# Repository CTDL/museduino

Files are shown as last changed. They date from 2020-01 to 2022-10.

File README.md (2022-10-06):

# museduino
an open source electronics environment for exhibits

Docs: <a href="https://museduino.org">museduino.org</a>

## PCB design files and Schematics

All files are under <a href="https://github.com/CTDL/museduino/tree/master/hardware">hardware</a>  folder and subdivided by PCB design software.

ExpressPCB folder contains versions 2.2 and below. Kicad folder is organized by board name contains its own versions (3.0 or greater).

View changelog.md for further information on changes between versions.

## Tutorials and Circuit Diagrams
Content for workshops and Museduino guides can be found under 
<a href="https://github.com/CTDL/museduino/tree/master/tutorials">tutorials</a> folder.

## Solder Instructions
Component guides and step-by-step instructions coming soon.
<a href="https://github.com/CTDL/museduino/tree/master/solder-instructions">solder-instructions</a> folder.

## Open Source
Museduino 4.0 is certified as OSHWA-compliant open source hardware.

<a href="https://certification.oshwa.org/us002128.html">certification.oshwa.org/us002128.html</a>

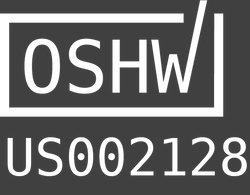
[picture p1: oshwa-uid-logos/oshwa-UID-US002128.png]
certification


## License

Licensing

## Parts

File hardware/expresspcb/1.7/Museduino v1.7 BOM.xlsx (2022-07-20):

BOM for Museduino v1.7 |  |  |  |  | ~cost
Part ID | Description |  |  | Vendor
D1 | T1 Green |  |  |  | 0.1
D2 | T1 Green |  |  |  | 0.1
D3 | T1 Green |  |  |  | 0.1
D4 | T1 Yellow |  |  |  | 0.1
J1 | 0.100 Header 8-pos |  |  |  | 0.1
J2 | 0.100 Header 8-pos |  |  |  | 0.1
J3 | 0.100 Header 6-pos |  |  |  | 0.1
J4 | 0.100 Header 6-pos |  |  |  | 0.1
J5 | RJ-45 Socket |  |  |  | 0.8
J6 | RJ-45 Socket |  |  |  | 0.8
J7 | RJ-45 Socket |  |  |  | 0.8
J8 | RJ-45 Socket |  |  |  | 0.8
J9 | Breadboard-friendly 2.1mm DC barrel jack[ID:373] |  |  | Adafruit | 0.86
J10 | RJ-45 Socket |  |  |  | 0.8
J11 | RJ-45 Socket |  |  |  | 0.8
J12 | 2.54mm/0.1" Pitch Terminal Block - 4-pin[ID:2137] |  |  | Adafruit | 1.4
J13 | RJ-45 Socket |  |  |  | 0.8
J14 | 2.54mm/0.1" Pitch Terminal Block - 4-pin[ID:2137] |  |  | Adafruit | 1.4
J15 | 2.54mm/0.1" Pitch Terminal Block - 4-pin[ID:2137] |  |  | Adafruit | 1.4
J16 | 2.54mm/0.1" Pitch Terminal Block - 4-pin[ID:2137] |  |  | Adafruit | 1.4
J17 | 2.54mm/0.1" Pitch Terminal Block - 4-pin[ID:2137] |  |  | Adafruit | 1.4
J18 | 2.54mm/0.1" Pitch Terminal Block - 4-pin[ID:2137] |  |  | Adafruit | 1.4
J19 | 0.100 4 pos male header |  |  |  | 0.1
J20 | 0.100 4 pos male header |  |  |  | 0.1
J21 | 0.100 4 pos male header |  |  |  | 0.1
J22 | 3.81mm terminal block | 1727010 (http://www.newark.com/webapp/wcs/stores/servlet/ProductDisplay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) |  | Newark | 1.04
J23 | 0.100 4 pos male header |  |  |  | 0.1
JP1 | 3 pos 0.100 jumper |  |  |  | 0.1
JP2 | 3 pos 0.100 jumper |  |  |  | 0.1
JP3 | 3 pos 0.100 jumper |  |  |  | 0.1
JP4 | 3 pos 0.100 jumper |  |  |  | 0.1
Q1 | TO-252 zxmn10A09K |  |  | Digikey | 1.4
Q2 | TO-252 zxmn10A09K |  |  |  | 1.4
Q3 | TO-252 zxmn10A09K |  |  |  | 1.4
R1 | 470 1/8W |  |  |  | 0.02
R2 | 220 |  |  |  | 0.02
R3 | 220 |  |  |  | 0.02
R4 | 470 |  |  |  | 0.02
R5 | 470 |  |  |  | 0.02
R6 | 470 |  |  |  | 0.02
R7 | 470 |  |  |  | 0.02
R8 | 470 |  |  |  | 0.02
R9 | 220 |  |  |  | 0.02
R10 | 1K |  |  |  | 0.02
SW1 | DPDT DIP GrayHill 76SD01T |  |  | Mouser | 3.3
SW2 | DPDT DIP GrayHill 76SD01T |  |  |  | 3.3
U1 | 7805 TO-220 |  |  |  | 0.5
 |  |  | Total Cost |  | 29 | plus other smorgasboard
 |  |  |  |  | Approximately $35 in parts.

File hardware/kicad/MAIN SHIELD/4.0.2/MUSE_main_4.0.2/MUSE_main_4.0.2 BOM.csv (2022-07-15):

Id | Designator | Package | Quantity | Designation | Supplier and ref
1 | J1,J4,J11,J14 | Pin_Header_Straight_1x08_Pitch2.54mm | 4 | CONN_01X08
2 | J2,J12 | Pin_Header_Straight_1x10_Pitch2.54mm | 2 | CONN_01X10
3 | J3,J13 | Pin_Header_Straight_1x06_Pitch2.54mm | 2 | CONN_01X06
4 | J5,J8,J6 | RJ45_8 | 3 | CONN_01X08
5 | J7 | RJ45_8 | 1 | CONN_01X08
6 | D1 | LED_D3.0mm | 1 | LED
7 | J9 | BARREL_JACK_RND | 1 | BARREL_JACK
8 | R1 | R_Axial_DIN0204_L3.6mm_D1.6mm_P7.62mm_Horizontal | 1 | 470
9 | U1 | TO-220_Horizontal | 1 | LM7805CT
10 | JP1 | Pin_Header_Straight_1x03_Pitch2.54mm | 1 | CONN_01X03
11 | JP5,JP6,JP2,JP3 | Pin_Header_Straight_2x03_Pitch2.54mm | 4 | CONN_02X03
12 | G*** | open_hdwe_rev | 1 | LOGO

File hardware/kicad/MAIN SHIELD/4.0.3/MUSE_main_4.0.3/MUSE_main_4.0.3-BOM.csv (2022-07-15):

Id | Designator | Package | Quantity | Designation | Supplier and ref
1 | JP1 | Pin_Header_Straight_1x03_Pitch2.54mm | 1 | CONN_01X03
2 | J6,J5,J8 | RJ45_8 | 3 | CONN_01X08
3 | J1,J4,J11,J14 | Pin_Header_Straight_1x08_Pitch2.54mm | 4 | CONN_01X08
4 | J2,J12 | Pin_Header_Straight_1x10_Pitch2.54mm | 2 | CONN_01X10
5 | J3,J13 | Pin_Header_Straight_1x06_Pitch2.54mm | 2 | CONN_01X06
6 | J7 | RJ45_8 | 1 | CONN_01X08
7 | D1 | LED_D3.0mm | 1 | LED
8 | U1 | TO-220_Horizontal | 1 | LM7805CT
9 | JP5,JP6,JP2,JP3 | Pin_Header_Straight_2x03_Pitch2.54mm | 4 | CONN_02X03
10 | R1 | R_Axial_DIN0204_L3.6mm_D1.6mm_P7.62mm_Horizontal | 1 | 470
11 | G*** | open_hdwe_rev | 1 | LOGO
12 | J9 | BARREL_JACK_RND | 1 | BARREL_JACK

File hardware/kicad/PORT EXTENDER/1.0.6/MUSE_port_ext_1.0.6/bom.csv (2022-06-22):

value | footprint | libsource/_lib | libsource/_part | libsource/_description | sheetpath/_names | sheetpath/_tstamps | tstamp | _ref | datasheet | fields/field/0/_name | fields/field/0/__text | fields/field/1/_name | fields/field/1/__text | fields/field/2/_name | fields/field/2/__text | fields/field/3/_name | fields/field/3/__text | fields/field/4/_name | fields/field/4/__text | fields/field/5/_name | fields/field/5/__text | fields/field/6/_name | fields/field/6/__text | fields/field/7/_name | fields/field/7/__text | fields/field/8/_name | fields/field/8/__text
RJ45_01X08 | Connectors:RJ45_8 | Connector_Generic | Conn_01x08 | Generic connector, single row, 01x08, script generated (kicad-library-utils/schlib/autogen/connector/) | / | / | 5A0F6021 | J1
RJ45_01X08 | Connectors:RJ45_8 | Connector_Generic | Conn_01x08 | Generic connector, single row, 01x08, script generated (kicad-library-utils/schlib/autogen/connector/) | / | / | 5A1D9F02 | J3
LED | LEDs:LED_D3.0mm | Device | LED | LED generic | / | / | 5A1DA0EA | D1
470 | Resistors_THT:R_Axial_DIN0204_L3.6mm_D1.6mm_P7.62mm_Horizontal | Device | R | Resistor | / | / | 5A1DA161 | R3
RJ45_01X08 | Connectors:RJ45_8 | Connector_Generic | Conn_01x08 | Generic connector, single row, 01x08, script generated (kicad-library-utils/schlib/autogen/connector/) | / | / | 5B0AEDCC | J4
RJ45_01X08 | Connectors:RJ45_8 | Connector_Generic | Conn_01x08 | Generic connector, single row, 01x08, script generated (kicad-library-utils/schlib/autogen/connector/) | / | / | 5B16A2C0 | J2
RJ45_01X08 | Connectors:RJ45_8 | Connector_Generic | Conn_01x08 | Generic connector, single row, 01x08, script generated (kicad-library-utils/schlib/autogen/connector/) | / | / | 5B16A32D | J5
CD74HC4051E | digikey-footprints:DIP-16_W7.62mm | dk_Interface-Analog-Switches-Multiplexers-Demultiplexers | CD74HC4051E | IC MUX/DEMUX 8X1 16DIP | / | / | 5B16ED2B | U4 | http://www.ti.com/lit/ds/symlink/cd74hc4051.pdf | Category | Integrated Circuits (ICs) | DK_Datasheet_Link | http://www.ti.com/lit/ds/symlink/cd74hc4051.pdf | DK_Detail_Page | /product-detail/en/texas-instruments/CD74HC4051E/296-12810-5-ND/475938 | Description | IC MUX/DEMUX 8X1 16DIP | Digi-Key_PN | 296-12810-5-ND | Family | Interface - Analog Switches, Multiplexers, Demultiplexers | MPN | CD74HC4051E | Manufacturer | Texas Instruments | Status | Active
CD74HC4067SM96 | digikey-footprints:SSOP-24_W5.30mm | dk_Interface-Analog-Switches-Multiplexers-Demultiplexers | CD74HC4067SM96 | IC MUX/DEMUX 1X16 24SSOP | / | / | 5B16F5DB | U3 | http://www.ti.com/lit/ds/symlink/cd74hc4067.pdf | Category | Integrated Circuits (ICs) | DK_Datasheet_Link | http://www.ti.com/lit/ds/symlink/cd74hc4067.pdf | DK_Detail_Page | /product-detail/en/texas-instruments/CD74HC4067SM96/296-9226-1-ND/376978 | Description | IC MUX/DEMUX 1X16 24SSOP | Digi-Key_PN | 296-9226-1-ND | Family | Interface - Analog Switches, Multiplexers, Demultiplexers | MPN | CD74HC4067SM96 | Manufacturer | Texas Instruments | Status | Active
MCP23017-E_SP | digikey-footprints:DIP-28_W7.62mm | dk_Interface-I-O-Expanders | MCP23017-E_SP | IC I/O EXPANDER I2C 16B 28SDIP | / | / | 5B1C5702 | U2 | http://www.microchip.com/mymicrochip/filehandler.aspx?ddocname=en023709 | Category | Integrated Circuits (ICs) | DK_Datasheet_Link | http://www.microchip.com/mymicrochip/filehandler.aspx?ddocname=en023709 | DK_Detail_Page | /product-detail/en/microchip-technology/MCP23017-E-SP/MCP23017-E-SP-ND/894272 | Description | IC I/O EXPANDER I2C 16B 28SDIP | Digi-Key_PN | MCP23017-E/SP-ND | Family | Interface - I/O Expanders | MPN | MCP23017-E/SP | Manufacturer | Microchip Technology | Status | Active
MCP23017-E_SP | digikey-footprints:DIP-28_W7.62mm | dk_Interface-I-O-Expanders | MCP23017-E_SP | IC I/O EXPANDER I2C 16B 28SDIP | / | / | 5B1C5A45 | U1 | http://www.microchip.com/mymicrochip/filehandler.aspx?ddocname=en023709 | Category | Integrated Circuits (ICs) | DK_Datasheet_Link | http://www.microchip.com/mymicrochip/filehandler.aspx?ddocname=en023709 | DK_Detail_Page | /product-detail/en/microchip-technology/MCP23017-E-SP/MCP23017-E-SP-ND/894272 | Description | IC I/O EXPANDER I2C 16B 28SDIP | Digi-Key_PN | MCP23017-E/SP-ND | Family | Interface - I/O Expanders | MPN | MCP23017-E/SP | Manufacturer | Microchip Technology | Status | Active
0.1 | Capacitors_THT:CP_Radial_Tantal_D4.5mm_P2.50mm | Device | CP | Polarised capacitor | / | / | 5B1DB3D3 | C1
10K | Resistors_THT:R_Axial_DIN0204_L3.6mm_D1.6mm_P7.62mm_Horizontal | Device | R | Resistor | / | / | 5B1E0CC2 | R1
RJ45_01X08 | Connectors:RJ45_8 | Connector_Generic | Conn_01x08 | Generic connector, single row, 01x08, script generated (kicad-library-utils/schlib/autogen/connector/) | / | / | 5B20212D | J6
RJ45_01X08 | Connectors:RJ45_8 | Connector_Generic | Conn_01x08 | Generic connector, single row, 01x08, script generated (kicad-library-utils/schlib/autogen/connector/) | / | / | 5B202153 | J7
RJ45_01X08 | Connectors:RJ45_8 | Connector_Generic | Conn_01x08 | Generic connector, single row, 01x08, script generated (kicad-library-utils/schlib/autogen/connector/) | / | / | 5B202174 | J8
RJ45_01X08 | Connectors:RJ45_8 | Connector_Generic | Conn_01x08 | Generic connector, single row, 01x08, script generated (kicad-library-utils/schlib/autogen/connector/) | / | / | 5B202231 | J10
RJ45_01X08 | Connectors:RJ45_8 | Connector_Generic | Conn_01x08 | Generic connector, single row, 01x08, script generated (kicad-library-utils/schlib/autogen/connector/) | / | / | 5B202257 | J9
10K | Resistors_THT:R_Axial_DIN0204_L3.6mm_D1.6mm_P7.62mm_Horizontal | Device | R | Resistor | / | / | 5B20789B | R2
10K | Resistors_THT:R_Axial_DIN0204_L3.6mm_D1.6mm_P7.62mm_Horizontal | Device | R | Resistor | / | / | 5B2AD4FA | R4
10K | Resistors_THT:R_Axial_DIN0204_L3.6mm_D1.6mm_P7.62mm_Horizontal | Device | R | Resistor | / | / | 5B2AE901 | R5
Conn_01x03 | Pin_Headers:Pin_Header_Straight_1x03_Pitch2.54mm | Connector_Generic | Conn_01x03 | Generic connector, single row, 01x03, script generated (kicad-library-utils/schlib/autogen/connector/) | / | / | 5B4A910C | JMP4
Conn_01x03 | Pin_Headers:Pin_Header_Straight_1x03_Pitch2.54mm | Connector_Generic | Conn_01x03 | Generic connector, single row, 01x03, script generated (kicad-library-utils/schlib/autogen/connector/) | / | / | 5B4A9348 | JMP5
Conn_01x03 | Pin_Headers:Pin_Header_Straight_1x03_Pitch2.54mm | Connector_Generic | Conn_01x03 | Generic connector, single row, 01x03, script generated (kicad-library-utils/schlib/autogen/connector/) | / | / | 5B4A93D5 | JMP6
Conn_01x03 | Pin_Headers:Pin_Header_Straight_1x03_Pitch2.54mm | Connector_Generic | Conn_01x03 | Generic connector, single row, 01x03, script generated (kicad-library-utils/schlib/autogen/connector/) | / | / | 5B4A7C88 | JMP1
Conn_01x03 | Pin_Headers:Pin_Header_Straight_1x03_Pitch2.54mm | Connector_Generic | Conn_01x03 | Generic connector, single row, 01x03, script generated (kicad-library-utils/schlib/autogen/connector/) | / | / | 5B4A7C8E | JMP2
Conn_01x03 | Pin_Headers:Pin_Header_Straight_1x03_Pitch2.54mm | Connector_Generic | Conn_01x03 | Generic connector, single row, 01x03, script generated (kicad-library-utils/schlib/autogen/connector/) | / | / | 5B4A7C94 | JMP3
Conn_01x09 | Pin_Headers:Pin_Header_Straight_1x09_Pitch2.54mm | Connector_Generic | Conn_01x09 | Generic connector, single row, 01x09, script generated (kicad-library-utils/schlib/autogen/connector/) | / | / | 5B4AA3C8 | J11
Conn_01x09 | Pin_Headers:Pin_Header_Straight_1x09_Pitch2.54mm | Connector_Generic | Conn_01x09 | Generic connector, single row, 01x09, script generated (kicad-library-utils/schlib/autogen/connector/) | / | / | 5B4B25C7 | J13
Conn_01x09 | Pin_Headers:Pin_Header_Straight_1x09_Pitch2.54mm | Connector_Generic | Conn_01x09 | Generic connector, single row, 01x09, script generated (kicad-library-utils/schlib/autogen/connector/) | / | / | 5B4B267D | J12
4.7K | Resistors_THT:R_Axial_DIN0204_L3.6mm_D1.6mm_P7.62mm_Horizontal | Device | R | Resistor | / | / | 5B625EDE | R6
4.7K | Resistors_THT:R_Axial_DIN0204_L3.6mm_D1.6mm_P7.62mm_Horizontal | Device | R | Resistor | / | / | 5B62623C | R7

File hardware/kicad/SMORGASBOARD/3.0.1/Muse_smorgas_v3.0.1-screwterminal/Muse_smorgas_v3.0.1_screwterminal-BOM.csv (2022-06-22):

Id | Designator | Package | Quantity | Designation | Supplier and ref
1 | J1,J2 | RJ45_8 | 2 | RJ45_01X08
2 | R1 | R_Axial_DIN0204_L3.6mm_D1.6mm_P7.62mm_Horizontal | 1 | 470
3 | Mount_hole,Mount_Hole | MountingHole_3.2mm_M3 | 2 | MountingHole_3.2mm_M3
4 | D1 | LED_D3.0mm | 1 | LED
5 | R2 | R_Axial_DIN0207_L6.3mm_D2.5mm_P10.16mm_Horizontal | 1 | 220
6 | R3,R4 | R_Axial_DIN0207_L6.3mm_D2.5mm_P10.16mm_Horizontal | 2 | 470
7 | J4,J5,J6,J7,J3 | Screw_Header_Straight_1x04_Pitch2.54mm | 5 | CONN_01X04
8 | Q1 | TO-251-1EP_IPAK_Horizontal_smorg | 1 | NTD3055L104-1G

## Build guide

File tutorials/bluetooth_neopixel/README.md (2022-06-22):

Puppet Theater Example Code

This code includes the Adafruit_BluefruitLE_nRF51 library.

Modified "Controller" Example to include Neopixel strand on pin 6. 

Dowload the Bluefruit LE Connect App to use color picker to change Neopixel color.

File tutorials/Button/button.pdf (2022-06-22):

# Button Tutorial

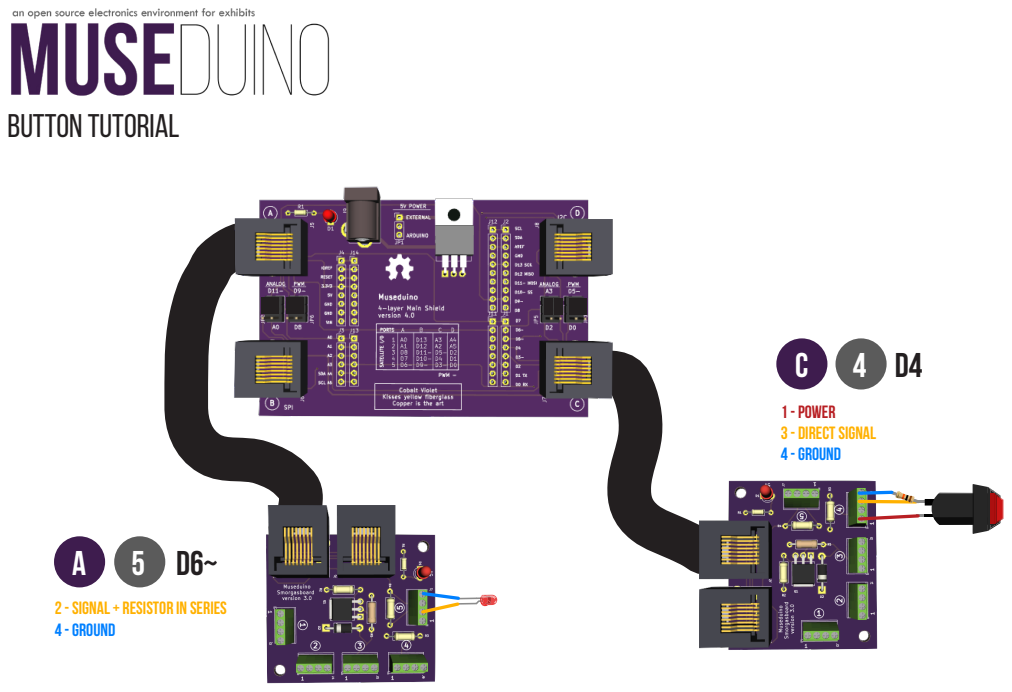
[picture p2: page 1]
1 - POWER 3 - Direct SIGNAL 4 - GROUND

2 - SIGNAL + RESISTOR IN SERIES
4 - GROUND

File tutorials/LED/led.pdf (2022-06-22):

# Button Tutorial

1 - POWER 3 - Direct SIGNAL 4 - GROUND

2 - SIGNAL + RESISTOR IN SERIES
4 - GROUND

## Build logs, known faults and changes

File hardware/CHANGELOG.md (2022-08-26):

# v4.0.3 (Dec 2019)

Fixed main shield labels on Analog select. 

# v4.0.2 (July 2018)

Kicad 5 update. Adjusted main shield labels.

Additional Satellite board named Port Extender is designed for projects that need to control more input and output devices.

#### Port Extender v1.0 
The Port Extender board was designed for use with the dedicated i2c port, Port D on the Main Shield and intended for projects that need to control more input and output devices. The Port Extender is equipped with two MCP23017 i2c 16-bit i/o digital port expanders, a CD74HC4051 8-channel multiplexer, and a CD74HC4067 16-channel multiplexer.  The Port Extender uses i2c pins (A4/A5 on Arduino Uno), analog pin (A3), and a PWM pin (D5~) in order to increase the number of usable digital, analog, and PWM pins.

# v4.0 (May 2018)

Adjusted main shield pin configuration. 

##### Analog Select on Main Shield

The Museduino main shield now allows distributed Analog pins to switch between ports. For example, pin D11~ on port B can switch places with pin A0 on port A. Pin A3 on Port C can also switch with Pin D2 on port D. This feature is useful when you need an extra Analog pin to be accessed from a different port. Intended for use with optional Port Extender.

##### New Distrubuted I/O

The Museduino shield distributes 20 Arduino pins between 4 CAT5/RJ-45 “ports”. A Satellite board connected on either port allows access to 5 specific Arduino pins to be used for sensors/actuators. The shield and satellite boards have a labeled solder mask to assist with configuration. Ports are labeled with a circled A, B, C, or D on the shield. The 5 Satellite I/O pins are labeled with a circled number 1 through 5 on the Satellite boards.

|  | A | B | C | D |	
| --- | --- | --- | --- | --- |
| 1 | A0  | D13  | * A3 | A4 |
| 2 | A1  | D12  | A2 | A5 |
| 3 | * D8  | D11~  | ** D5~ | * D2 |
| 4  | D7  | D10~  | D4 | D1 |
| 5  | D6~  | * D9~  | D3~ | ** D0 |

~ arduino pwm pin
* pwm switch

** analog switch

# v3 (Jan 2018)

All boards redesigned with Kicad 4. No functionaly changed, but replaced DPDT switch on main shield due to cost increase.  

Printed small run for testing purposes. 

# v2.2 (June 2015) 

Designed with Express PCB

No changes to schematic. Improved parts layout on pcb. 

# v2.0 (June 2015)

Designed with Express PCB. 

All i/o on satellite boards now use 4 pin screw terminals instead of header pins.

Improvements to overall pcb label design. Ports and satellite i/o labels use circled letter or number to match charts in documentation. 

##### New Distrubuted I/O labels

The Museduino distributes 5 different Arduino pins on ports A, B, C, or D labeled on the shield. A satellite connected on either port allows access to pins labeled 1, 2, 3, 4, or 5.

| ports | A | B | C | D |
| --- | --- | --- | --- | --- |
| 1 | A0  | D13  | A2 | A4 |
| 2 | A1  | D12  | A3 | A5 |
| 3 | * D8  | D11~  | D5~ | * D2 |
| 4 | D7  | D10~  | D4 | D1 |
| 5 | D6~  | * D9~  | * D3~ | D0 |

~ arduino pwm pin
* pwm switch

# v1.7 (May 2015)
Designed with Express PCB

Simplified labelling for Distributed I/O on all boards and chart using letters and numbers.

##### New Distrubuted I/O chart

The Museduino distributes 5 different Arduino pins on ports A, B, C, or D labeled on the shield. A satellite (S) connected on either port allows access to arduino pins labeled 1, 2, 3, 4, or 5.

| s | A | B | C | D |
| --- | --- | --- | --- | --- |
| 1 | A0  | D13  | A2 | A4 |
| 2 | A1  | D12  | A3 | A5 |
| 3 | * D8  | D11~  | D5~ | * D2 |
| 4 | D7  | D10~  | D4 | D1 |
| 5 | D6~  | * D9~  | * D3~ | D0 |

~ arduino pwm pin
* pwm switch

# v1.5 (March 2015)

Designed with Express PCB

New labels on PCB and to match Distributed I/O chart.

Main shield allows distributed PWM pins to switch between ports (cat5 pinout). For example, pin D9~ on port B can switch places with pin D8 on port A. Pin D3~ on Port D can also switch with Pin D2 on port C. This feature is useful when you need an extra PWM pin to be accessed from a Satellite board.

#### Smorgasboard 
Smorgasboard satellite board has 5 sets of headers for connecting to sensors/actuators labeled A through E in the schematic. Each i/o has its own pin configuration. 

A, B - power, signal pin, signal pin, ground pin
C - power, signal with open drain to ground (mosfet), direct signal, ground pin
D, E - power, signal pin with resistor n series, signal pin, ground pin

##### External Power board 
Additional Satellite board named External Power board is designed for sensor and actuators that require their own external power supply (NeoPixels, DC Motors, etc). Since satellites connected via CAT5 cables can be as long or short as needed, this board is particularly useful for large-scale installations.

External Power satellite board has 5 sets of headers for connecting to sensors/actuators labeled A through E in the schematic. Each i/o has its own pin configuration.  

A, B - power, signal pin, signal pin, ground pin
C, E - power, signal with open drain to ground (mosfet), direct signal, ground pin
D - power, signal pin, signal pin with resistor n series, ground pin

C, D and E contains a jumper that allows you to switch voltage between 5v from cat5, or voltage from the external power source. 

##### New Distrubuted I/O chart

The Museduino distributes 5 different Arduino pins on ports A, B, C, or D labeled on the shield. A satellite (S) connected on either port allows access to the specified Arduino pins used for sensors/actuators. 

| s  | s | A | B | C | D |
| --- | --- | --- | --- | --- | --- |
| smorgasboard pins  |  ext power pins | j5 | j6 | j8 | j7 |	
| j14 | j19 | A0  | D13  | A2 | A4 |
| j16  | j20 | A1  | D12  | A3 | A5 |
| j12  | j21 | * D8  | D11~  | D5~ | * D2 |
| j15  | j18 | D7  | D10~  | D4 | D1 |
| j17  | j23 | D6~  | * D9~  | * D3~ | D0 |

~ arduino pwm pin
* pwm switch

# v1.3

Designed with Express PCB. Printed small run for testing purposes. 

Changes to pin configuration to allow for pin swapping between between PWM pins.  

##### PWM Switches

v1.3 Main shield allows distributed PWM pins to switch between ports. For example, pin D9~ on j6 can switch places with pin D8 on j5. Pin D3~ on j7 can also switch with Pin D2 on j8. This feature is useful when you need an extra PWM pin to be accessed from a Satellite board.

#### Smorgasboard 
Smorgasboard satellite board has 5 sets of header pins for connecting to sensors/actuators. Each i/o has its own power, signal pin, optional signal pin with resistor in series, and ground pin. 

##### Distrubuted I/O chart

| pins  | j5 | j6 | j7 | j8 |	
| --- | --- | --- | --- | --- |
| j14 | A0  | D13  | A4 | A2 |
| j16  | A1  | D12  | A5 | A3 |
| j12  | * D8  | D11~  | * D2 | D5~ |
| j15  | D7  | D10~  | D1 | D4 |
| j17  | D6~  | * D9~ | D0 | * D3~ |

~ arduino pwm pin
* pwm switch

# v1.0 (Dec 2014)

Designed with Express PCB

The Museduino distributes Arduino Uno pins via Smorgasboard Satellites boards connected to CAT5/RJ45 ports on the main shield. Each port allows access to 5 distinct Arduino pins used for sensors/actuators.

The Museduino shield includes an external power jumper which allows for choice in power supply: 5V from the Arduino or an external source.

The Satellite board, named smorgasboard has pinout to allow for a wide range of sensor and actuator configurations from any CAT5/RJ45 port.

##### Distrubuted I/O chart

| pins  | j5 | j6 | j7 | j8 |	
| --- | --- | --- | --- | --- |
| j14 | A0  | D13  | A4 | A2 |
| j16  | A1  | D12  | A5 | A3 |
| j12  | D8  | D11~  | D2 | D5~ |
| j15  | D7  | D10~  | D1 | D4 |
| j17  | D6~  | D9~  | D0 | D3~ |

~ arduino pwm pin

#### Smorgasboard 
Smorgasboard satellite board has row of ground and power pins and 5 connections for various types of i/o.

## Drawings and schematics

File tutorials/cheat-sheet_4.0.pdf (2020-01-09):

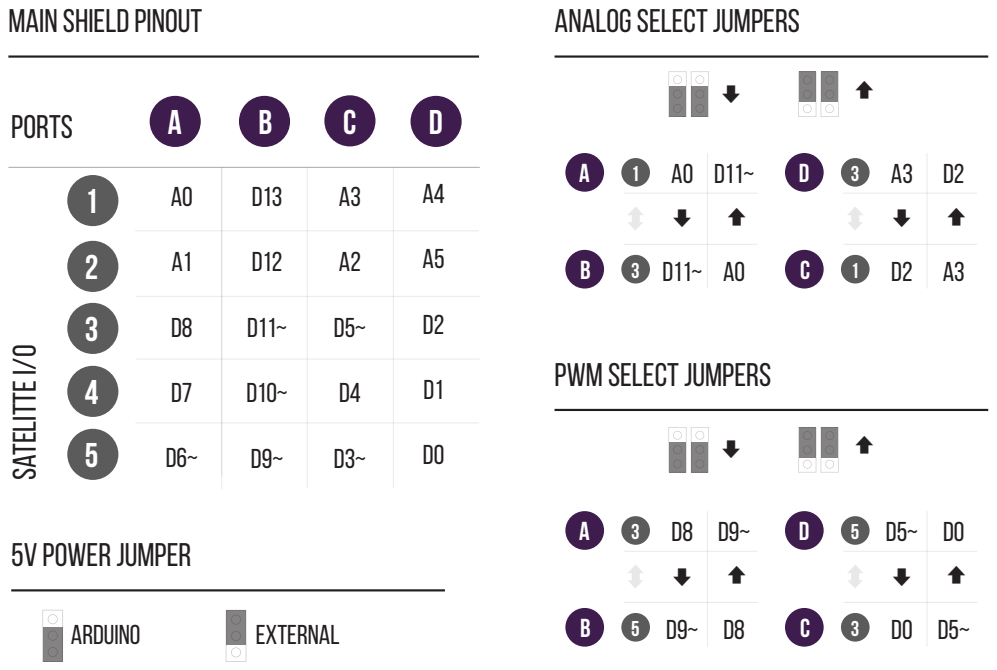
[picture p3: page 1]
SatelitTe I/O; Ports; 5v POWER JUMPER; ARDUINO; EXTERNAL

Main Shield Pinout

ANALOG SELECT JUMPERS

PWM SELECT JUMPERS

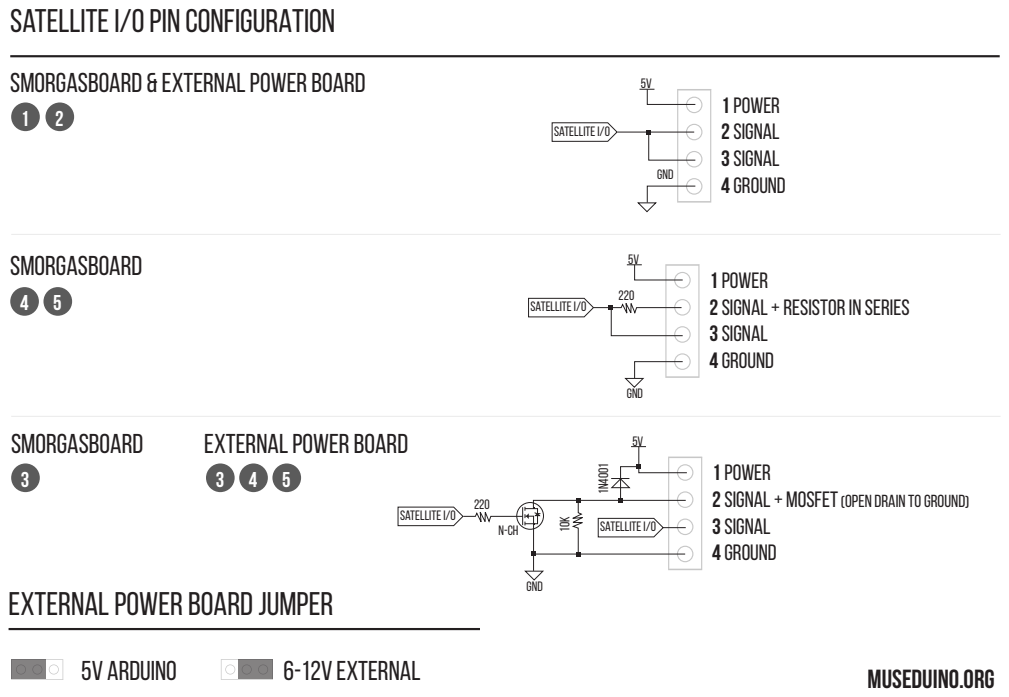
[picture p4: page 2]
SMOrgasboard; 5v ARDUINO; 6-12V EXTERNAL; Museduino.org; 1 Power 2 SIgnal 3 SIGNAL 4 GROUND; SatelliTe i/0; GND; SatelliTe i/0 ¹N400¹

Satellite i/0 PIN CONFIGURATION

SMOrgasboard & External PoWer BOARD

1 POWER
2 SIGNAl + Resistor in SeriEs
3 SIGNAL
4 GROUND

EXTERNAL POWER BOARD

2 SIGNAL + MOSFET(open Drain to GROUND)
3 SIGNAl

EXTERNAL POWER Board JUMPER

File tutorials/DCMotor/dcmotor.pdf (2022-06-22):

# DC Motor Tutorial

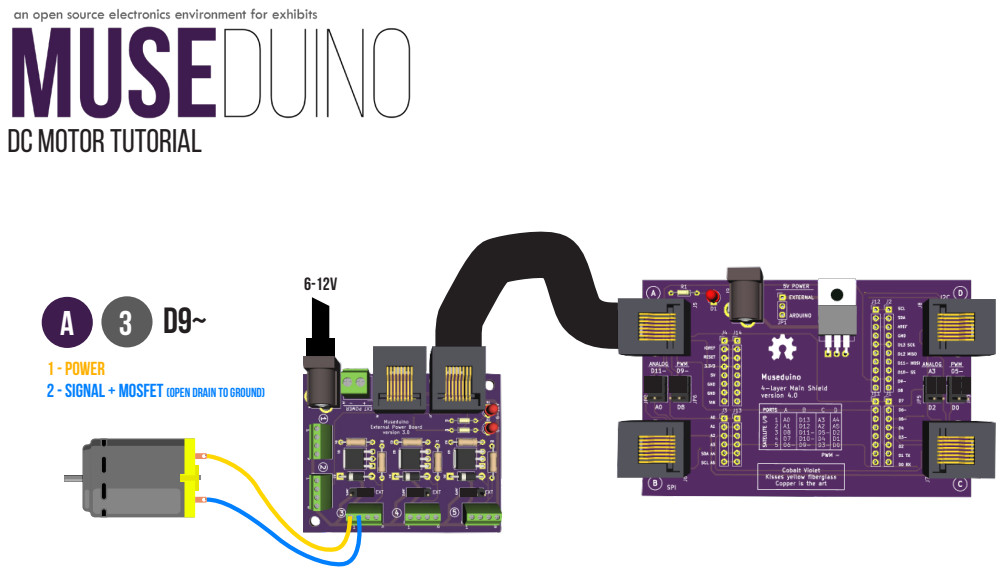
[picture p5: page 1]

1 - POWER
2 - SIGNAL + Mosfet (open DRAIN TO GROUND)

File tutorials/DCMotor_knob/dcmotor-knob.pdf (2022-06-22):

# DC Motor Knob Tutorial

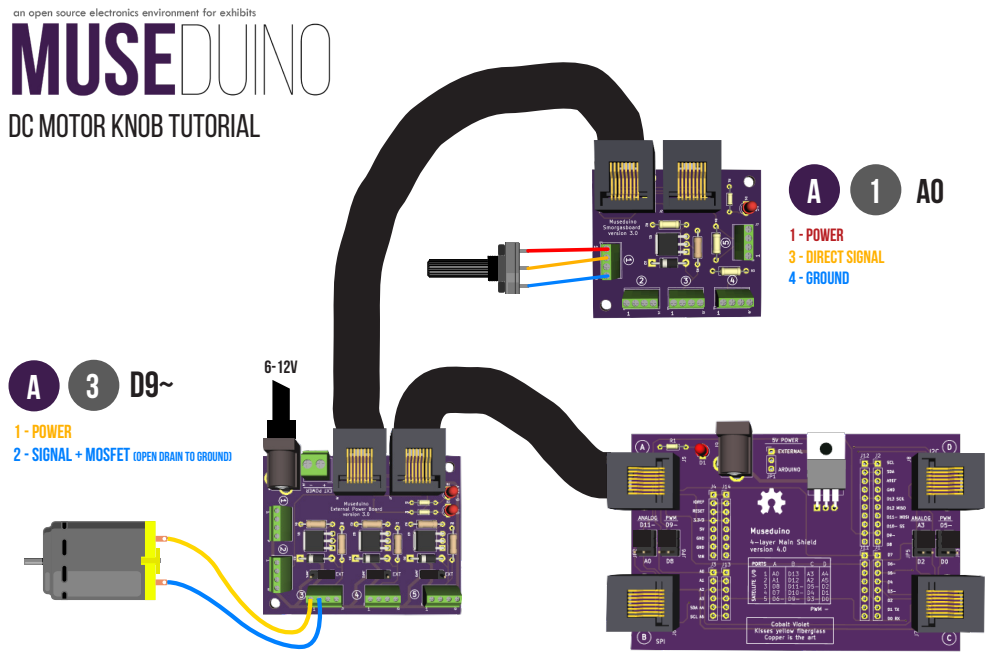
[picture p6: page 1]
1 - POWER 3 - Direct SIGNAL; 4 - GROUND A

1 - POWER
2 - SIGNAL + Mosfet (open DRAIN TO GROUND)

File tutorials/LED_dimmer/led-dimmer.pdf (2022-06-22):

## LED DIMMER Tutorial

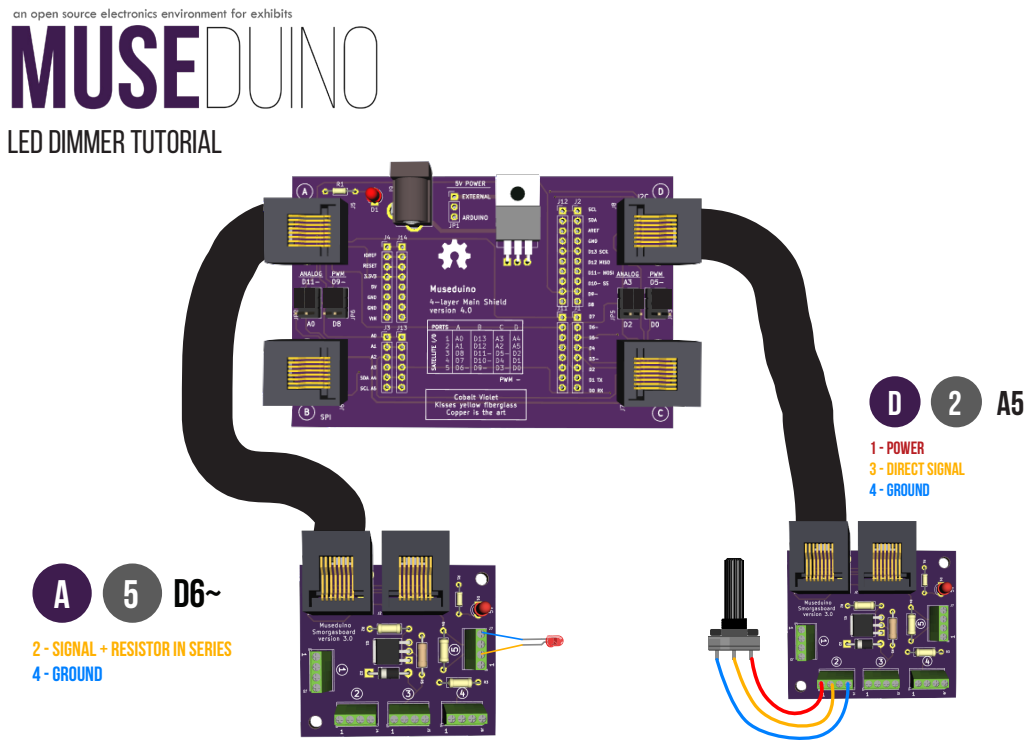
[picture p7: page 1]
1 - POWER 3 - Direct SIGNAL 4 - GROUND

2 - SIGNAL + RESISTOR IN SERIES
4 - GROUND

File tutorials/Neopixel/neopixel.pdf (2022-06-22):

## NEOPIXEL (External Power) Tutorial

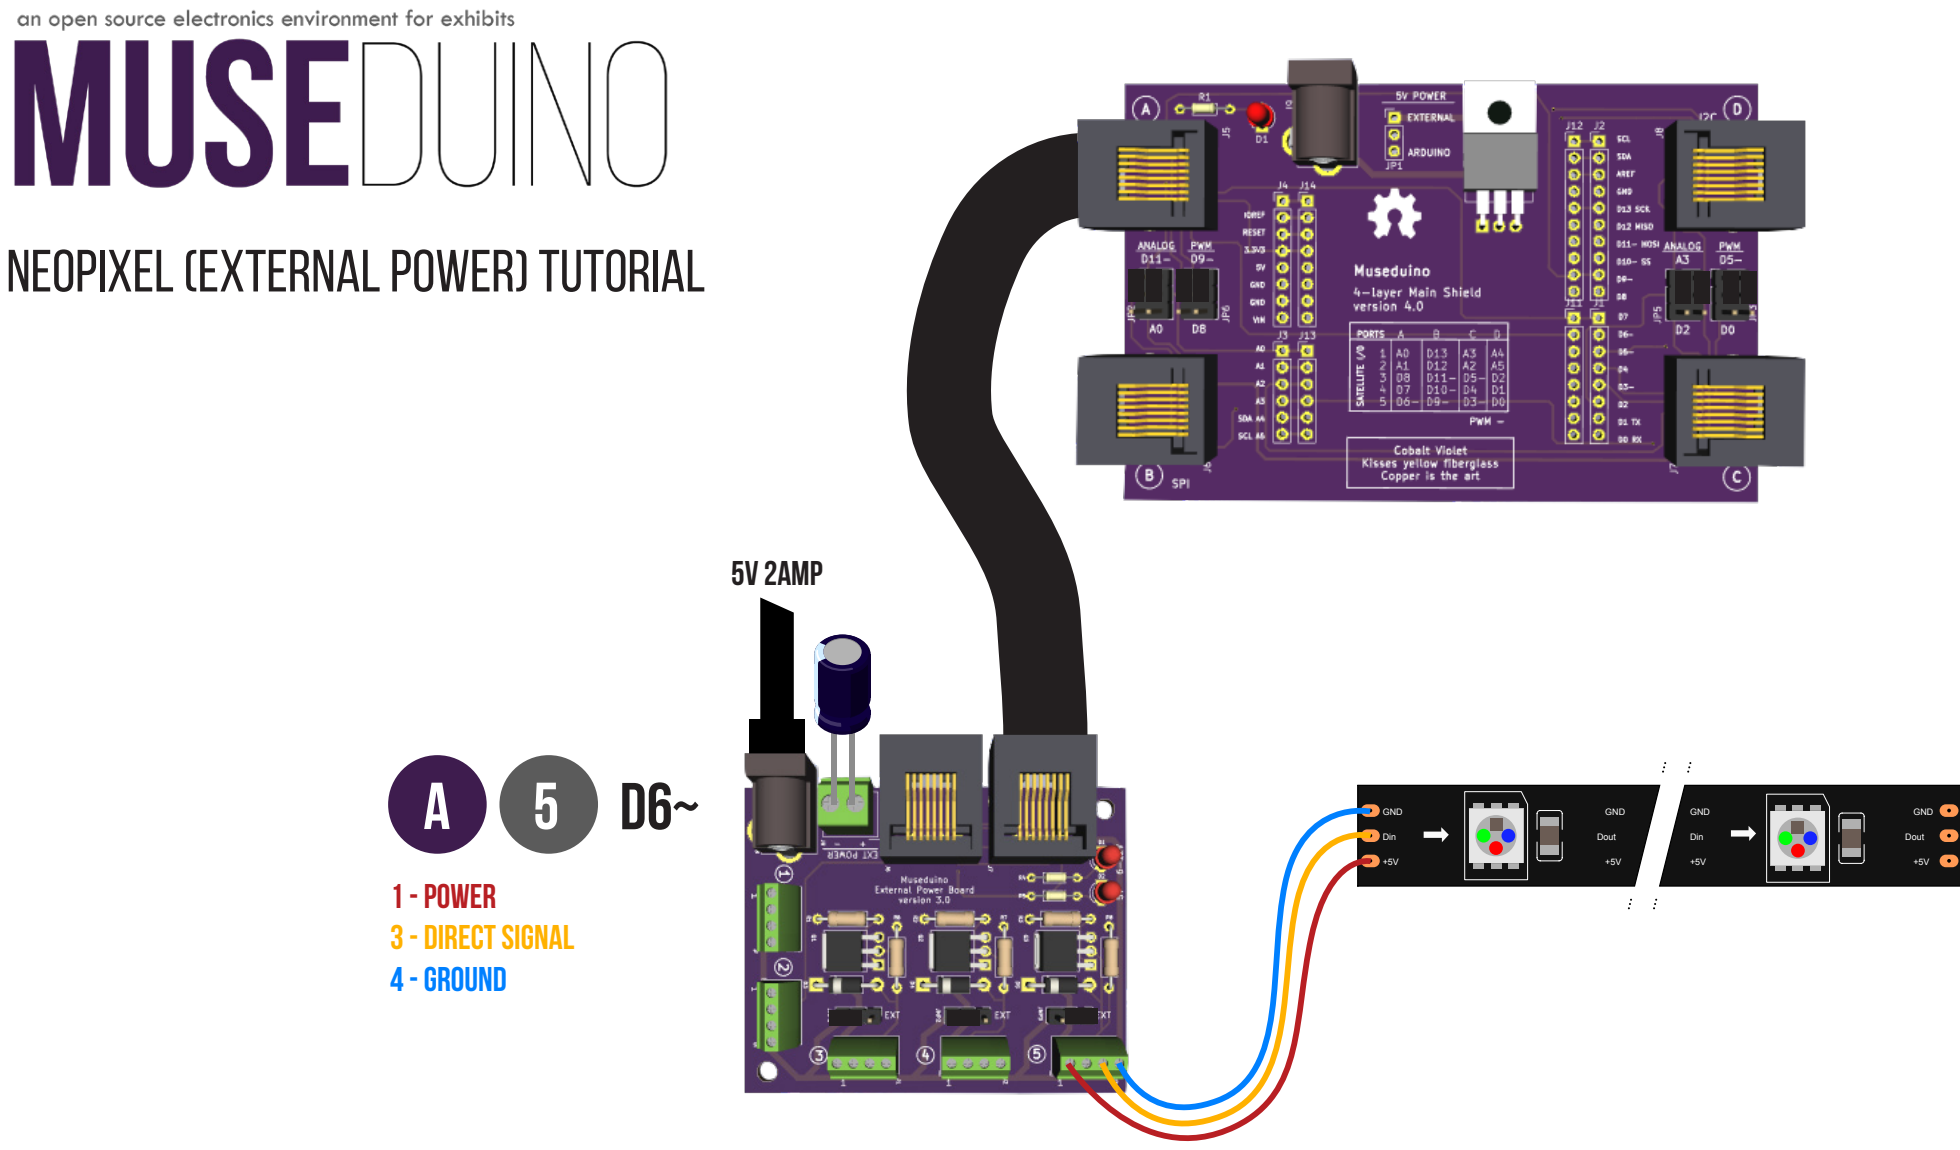
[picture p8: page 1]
5V 2AMP; GND; Din; Dout; 1 - POWER 3 - Direct SIGNAL 4 - GROUND

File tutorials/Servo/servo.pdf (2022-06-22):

# SERVO Motor SWeep (PWM SELECT) Tutorial

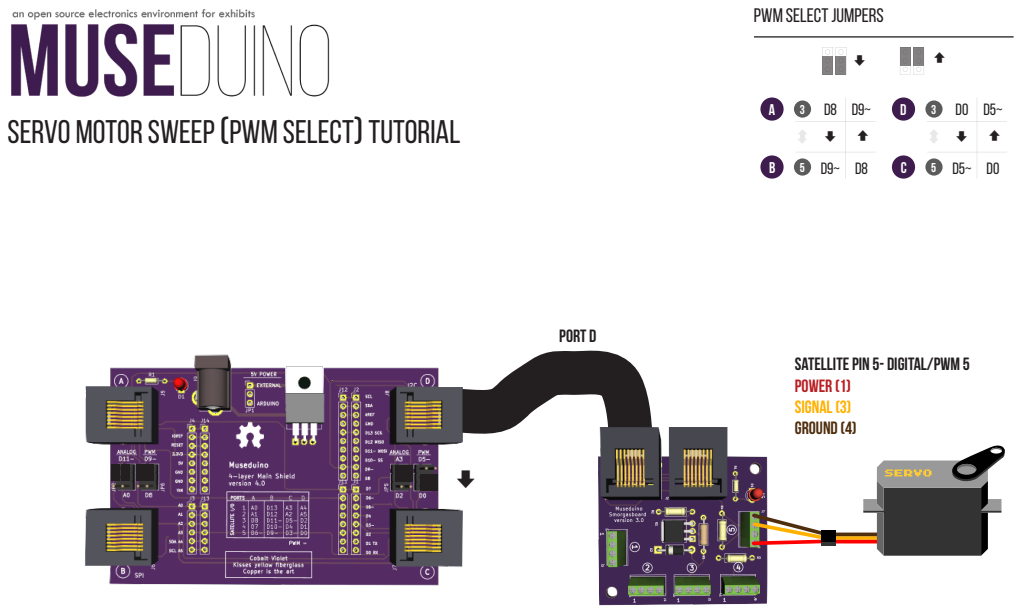
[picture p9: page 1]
PORT D

PWM SELECT JUMPERS

Satellite pin 5- digital/PWM 5
POWER (1)
SIGNAL (3)
GROUND (4)

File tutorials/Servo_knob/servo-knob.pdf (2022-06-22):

# SERVO Motor Knob (ANALOG SELECT) Tutorial

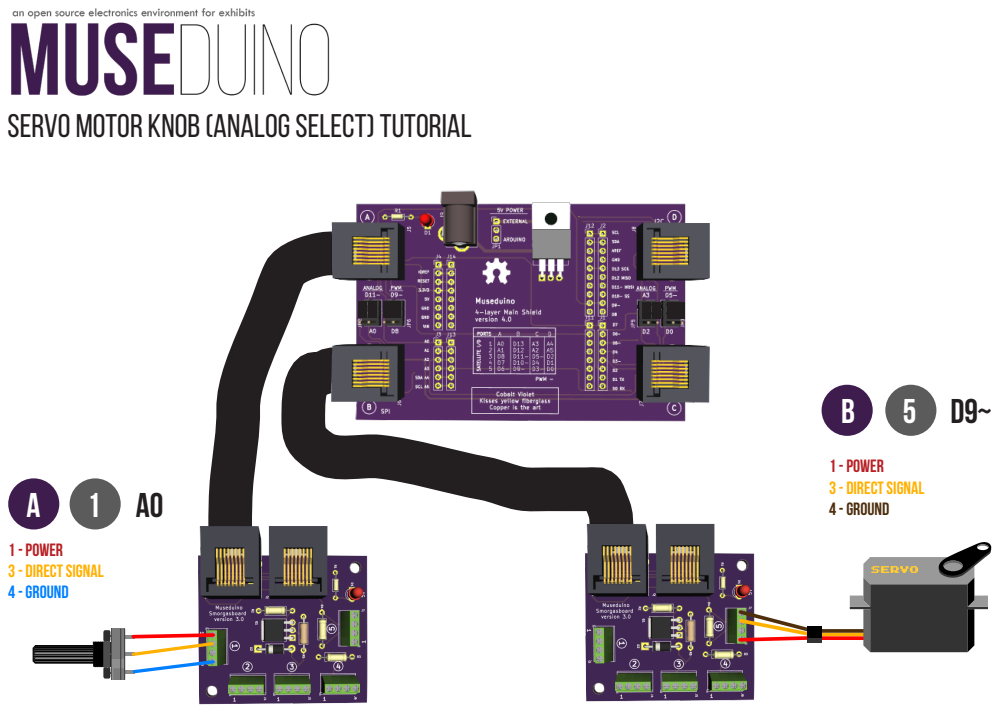
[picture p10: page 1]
1 - POWER 3 - Direct SIGNAL 4 - GROUND

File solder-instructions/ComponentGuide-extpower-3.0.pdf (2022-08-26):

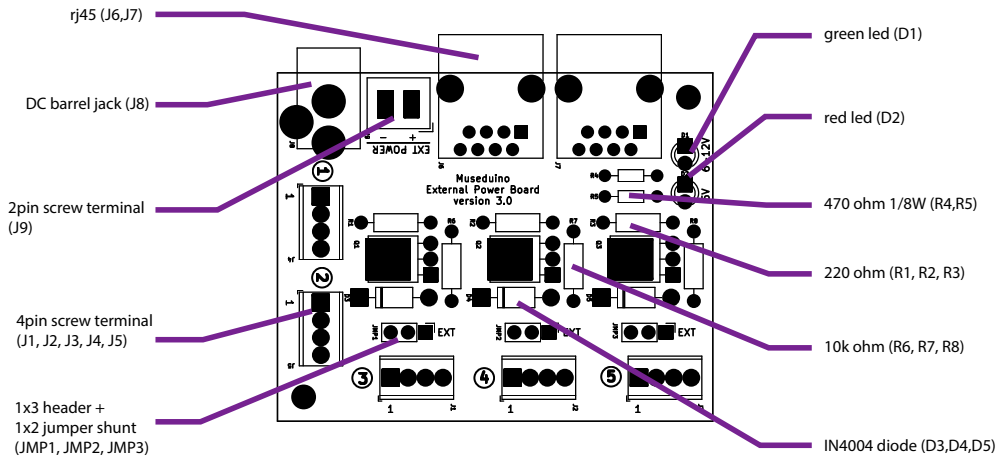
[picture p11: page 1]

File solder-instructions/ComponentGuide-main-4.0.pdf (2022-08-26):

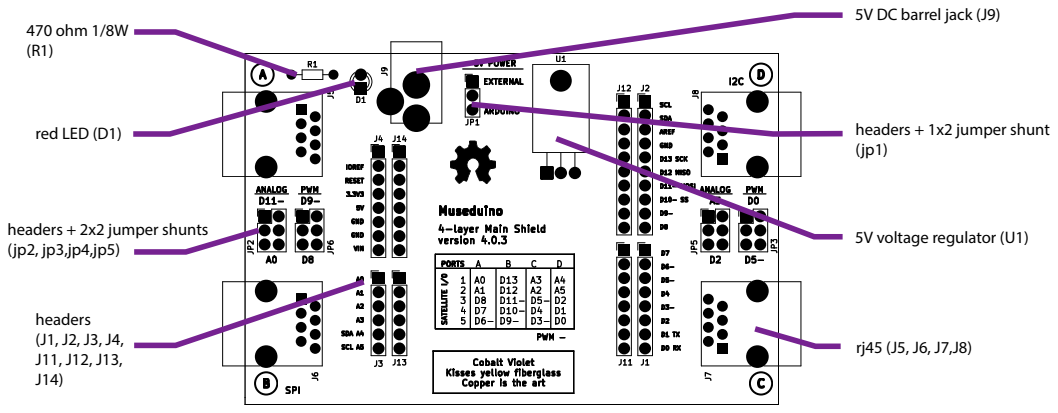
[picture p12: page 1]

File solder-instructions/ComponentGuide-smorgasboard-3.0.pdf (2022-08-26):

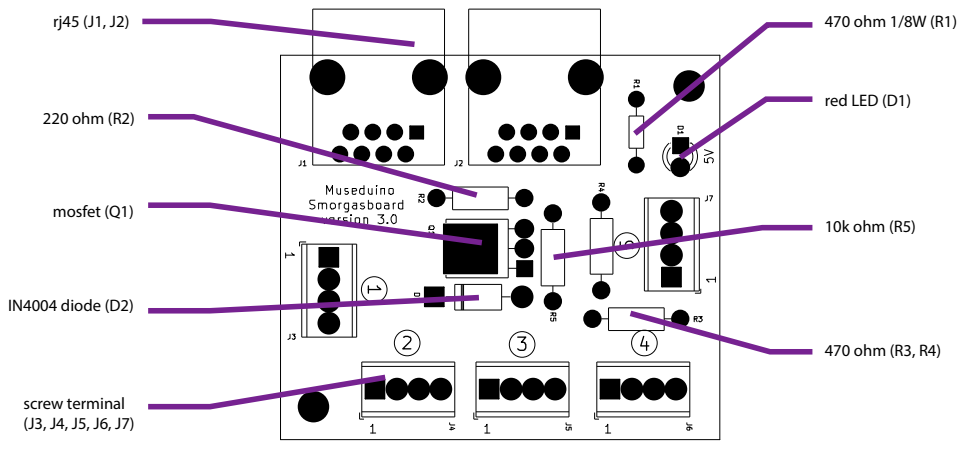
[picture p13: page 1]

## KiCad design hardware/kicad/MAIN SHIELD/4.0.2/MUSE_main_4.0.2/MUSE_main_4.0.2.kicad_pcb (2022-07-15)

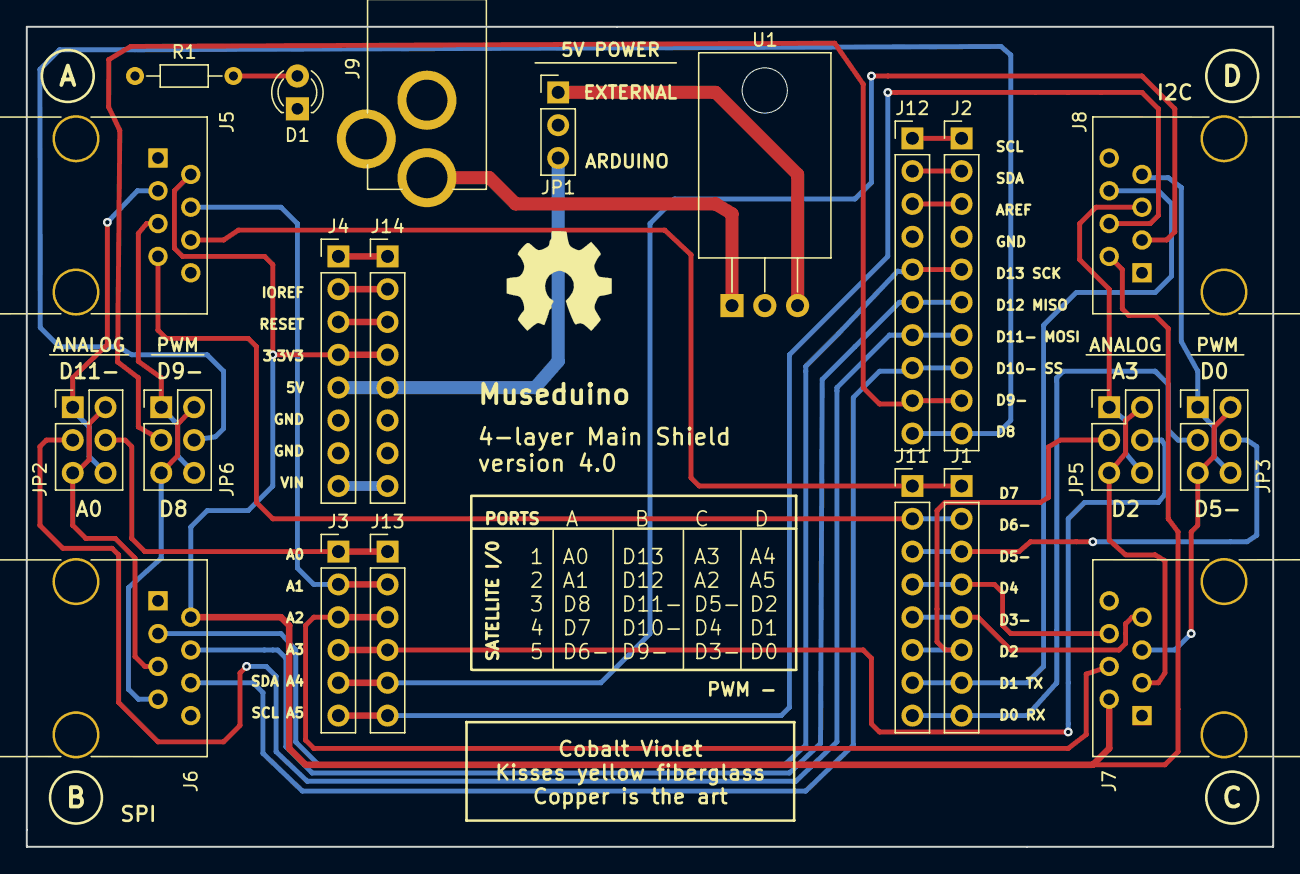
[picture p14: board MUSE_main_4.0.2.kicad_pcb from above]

Board: 4 copper layers, 96.5 x 63.5 mm, 21 parts (0 on the bottom side), 42 nets.

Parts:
D1: LED; LED_D3.0mm
J1, J4, J11, J14: CONN_01X08; Pin_Header_Straight_1x08_Pitch2.54mm
J2, J12: CONN_01X10; Pin_Header_Straight_1x10_Pitch2.54mm
J3, J13: CONN_01X06; Pin_Header_Straight_1x06_Pitch2.54mm
J5, J6, J7, J8: CONN_01X08; RJ45_8
J9: BARREL_JACK; BARREL_JACK_RND
JP1: CONN_01X03; Pin_Header_Straight_1x03_Pitch2.54mm
JP2, JP3, JP5, JP6: CONN_02X03; Pin_Header_Straight_2x03_Pitch2.54mm
R1: 470; R_Axial_DIN0204_L3.6mm_D1.6mm_P7.62mm_Horizontal
U1: LM7805CT; TO-220_Horizontal

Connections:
+3V3: J4.4, J5.2, J6.2, J7.2, J8.2, J14.4
+5V: J5.1, J6.1, J7.1, J8.1, JP1.2, R1.1
+5V-ARD: J4.5, J14.5, JP1.3
+5V_REG: JP1.1, U1.3
A0: J3.1, J13.1, JP2.4
A1: J3.2, J5.4, J13.2
A2: J3.3, J7.4, J13.3
A3: J3.4, J13.4, JP5.4
A4_SDA: J3.5, J8.3, J13.5
A5_SCL: J3.6, J8.4, J13.6
AREF: J2.3, J12.3
D0: J1.8, J11.8, JP3.3
D1: J1.7, J8.6, J11.7
D2: J1.6, J11.6, JP5.3
D3: J1.5, J7.7, J11.5
D4: J1.4, J7.6, J11.4
D5: J1.3, J11.3, JP3.4
D6: J1.2, J5.7, J11.2
D7: J1.1, J5.6, J11.1
D8: J2.10, J12.10, JP6.4
D9: J2.9, J12.9, JP6.3
D10: J2.8, J6.6, J12.8
D11: J2.7, J12.7, JP2.3
D12: J2.6, J6.4, J12.6
D13: J2.5, J6.3, J12.5
GND: D1.1, J2.4, J4.6, J4.7, J5.8, J6.8, J7.8, J8.8, J9.2, J12.4, J14.6, J14.7, U1.2
IO-REF: J4.2, J14.2
J2-1: J2.1, J12.1
J2-2: J2.2, J12.2
J4-1: J4.1, J14.1
J5-3: J5.3, JP2.1, JP2.6
J5-5: J5.5, JP6.1, JP6.6
J6-5: J6.5, JP2.2, JP2.5
J6-7: J6.7, JP6.2, JP6.5
J7-3: J7.3, JP5.2, JP5.5
J7-5: J7.5, JP3.2, JP3.5
J8-5: J8.5, JP5.1, JP5.6
J8-7: J8.7, JP3.1, JP3.6
unnamed: D1.2, R1.2
unnamed: J9.1, U1.1
RST: J4.3, J14.3
Vin: J4.8, J14.8

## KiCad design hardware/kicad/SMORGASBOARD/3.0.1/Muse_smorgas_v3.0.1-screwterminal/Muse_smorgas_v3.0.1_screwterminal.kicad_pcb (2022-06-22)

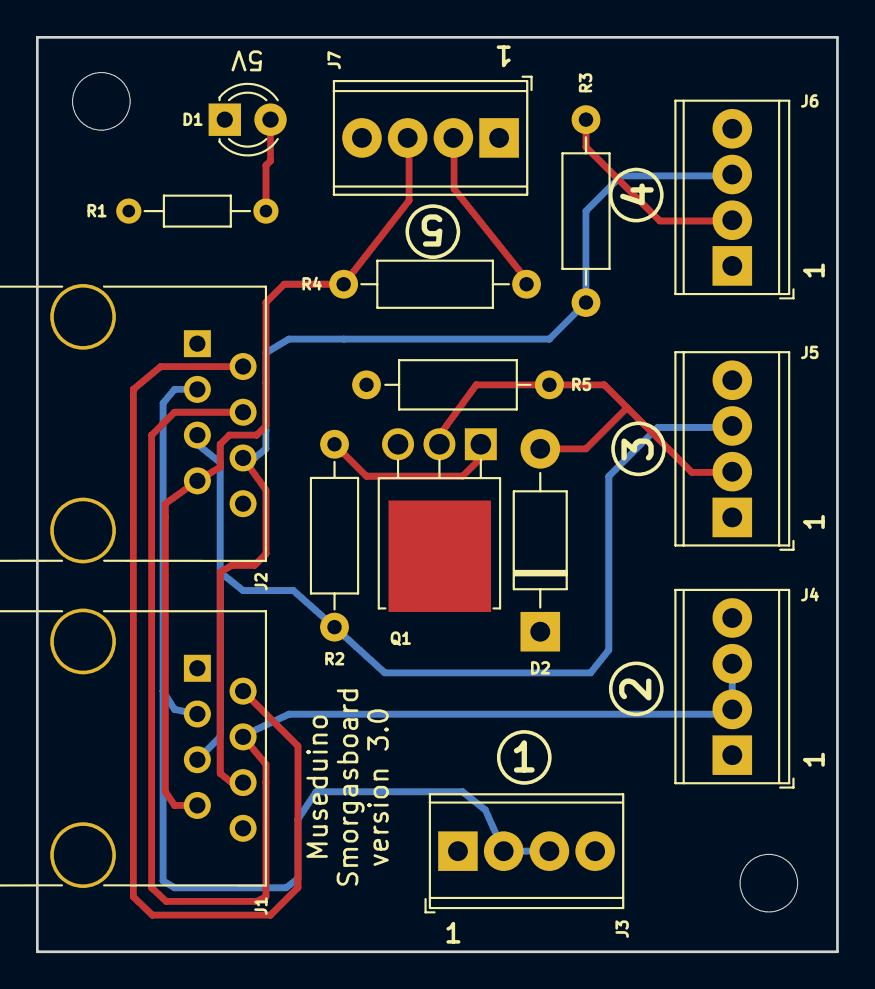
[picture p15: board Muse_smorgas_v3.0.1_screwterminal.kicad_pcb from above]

Board: 4 copper layers, 44.5 x 50.8 mm, 17 parts (0 on the bottom side), 13 nets.

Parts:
D1: LED; LED_D3.0mm
D2: 1N4001; D_DO-41_SOD81_P10.16mm_Horizontal
J1, J2: RJ45_01X08; RJ45_8
J3, J4, J5, J6, J7: CONN_01X04; TerminalBlock_Phoenix_MPT-0,5-4-2.54_1x04_P2.54mm_Horizontal
Mount_Hole: MountingHole_3.2mm_M3
Mount_hole: MountingHole_3.2mm_M3
Q1: NTD3055L104-1G; TO-251-1EP_IPAK_Horizontal_smorg
R1: 470; R_Axial_DIN0204_L3.6mm_D1.6mm_P7.62mm_Horizontal
R2: 220; R_Axial_DIN0207_L6.3mm_D2.5mm_P10.16mm_Horizontal
R3, R4: 470; R_Axial_DIN0207_L6.3mm_D2.5mm_P10.16mm_Horizontal
R5: 10k; R_Axial_DIN0207_L6.3mm_D2.5mm_P10.16mm_Horizontal

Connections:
+3V3: J1.2, J2.2
+5V: D2.1, J1.1, J2.1, J3.1, J4.1, J5.1, J6.1, J7.1, R1.1
GND: D1.1, J1.8, J2.8, J3.4, J4.4, J5.4, J6.4, J7.4, Q1.3, R5.2
unnamed: D1.2, R1.2
unnamed: D2.2, J5.2, Q1.2, R5.1
unnamed: J6.2, R3.2
unnamed: J7.2, R4.2
unnamed: Q1.1, R2.1
Sense_1: J1.3, J2.3, J3.2, J3.3
Sense_2: J1.4, J2.4, J4.2, J4.3
Sense_3: J1.5, J2.5, J5.3, R2.2
Sense_4: J1.6, J2.6, J6.3, R3.1
Sense_5: J1.7, J2.7, J7.3, R4.1

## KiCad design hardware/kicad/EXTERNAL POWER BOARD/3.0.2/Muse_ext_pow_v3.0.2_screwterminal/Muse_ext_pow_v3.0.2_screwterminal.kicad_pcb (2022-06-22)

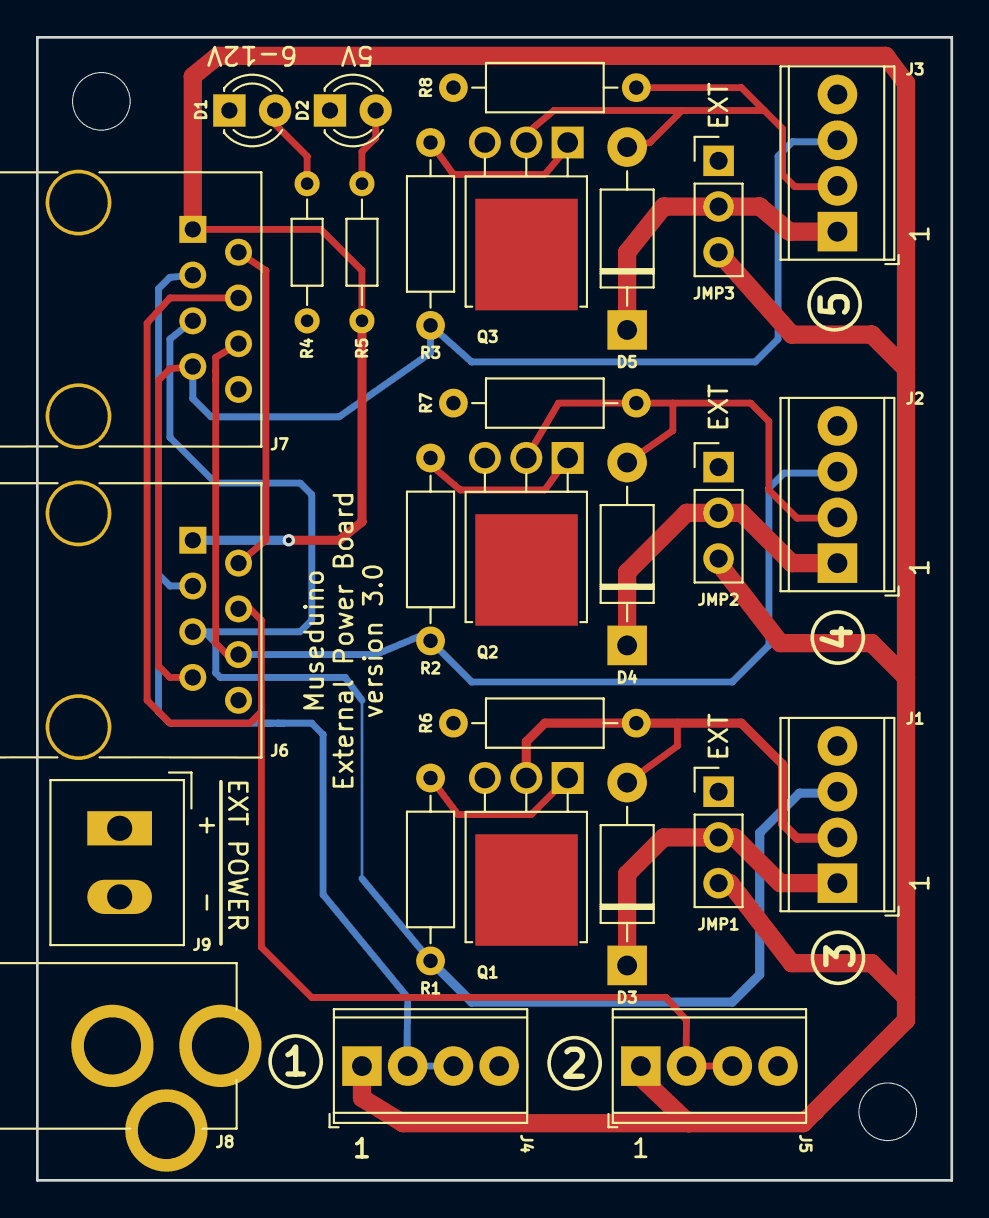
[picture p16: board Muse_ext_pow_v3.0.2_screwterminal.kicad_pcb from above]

Board: 4 copper layers, 50.8 x 63.5 mm, 30 parts (0 on the bottom side), 20 nets.

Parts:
D1, D2: LED; LED_D3.0mm
D3, D4, D5: 1N4001; D_DO-41_SOD81_P10.16mm_Horizontal
J1, J2, J3, J4, J5: CONN_01X04; TerminalBlock_Phoenix_MPT-0,5-4-2.54_1x04_P2.54mm_Horizontal
J6, J7: RJ45_01X08; RJ45_8
J8: Barrel_Jack; BARREL_JACK_RND
J9: Conn_01x02; FCI_3.81-mm_screw_terminal
JMP1, JMP2, JMP3: Conn_01x03_Male; Pin_Header_Straight_1x03_Pitch2.54mm
Mount_Hole: MountingHole_3.2mm_M3
Mount_hole: MountingHole_3.2mm_M3
Q1, Q2, Q3: NTD3055L104-1G; TO-251-1EP_IPAK_Horizontal_smorg
R1, R2, R3: 220; R_Axial_DIN0207_L6.3mm_D2.5mm_P10.16mm_Horizontal
R4, R5: 470; R_Axial_DIN0204_L3.6mm_D1.6mm_P7.62mm_Horizontal
R6, R7, R8: 10k; R_Axial_DIN0207_L6.3mm_D2.5mm_P10.16mm_Horizontal

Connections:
+3V3: J6.2, J7.2
+5V: J4.1, J5.1, J6.1, J7.1, JMP1.3, JMP2.3, JMP3.3, R5.1
GND: D1.1, D2.1, J1.4, J2.4, J3.4, J4.4, J5.4, J6.8, J7.8, J8.2, J9.2, Q1.3, Q2.3, Q3.3, R6.2, R7.2, R8.2
unnamed: D1.2, R4.2
unnamed: D2.2, R5.2
unnamed: D3.2, J1.2, Q1.2, R6.1
unnamed: D4.2, J2.2, Q2.2, R7.1
unnamed: D5.2, J3.2, Q3.2, R8.1
unnamed: Q1.1, R1.1
unnamed: Q2.1, R2.1
unnamed: Q3.1, R3.1
Sense_1: J4.2, J4.3, J6.3, J7.3
Sense_2: J5.2, J5.3, J6.4, J7.4
Sense_3: J1.3, J6.5, J7.5, R1.2
Sense_4: J2.3, J6.6, J7.6, R2.2
Sense_5: J3.3, J6.7, J7.7, R3.2
Ve3: D3.1, J1.1, JMP1.2
Ve4: D4.1, J2.1, JMP2.2
Ve5: D5.1, J3.1, JMP3.2
Vext: J8.1, J9.1, JMP1.1, JMP2.1, JMP3.1, R4.1

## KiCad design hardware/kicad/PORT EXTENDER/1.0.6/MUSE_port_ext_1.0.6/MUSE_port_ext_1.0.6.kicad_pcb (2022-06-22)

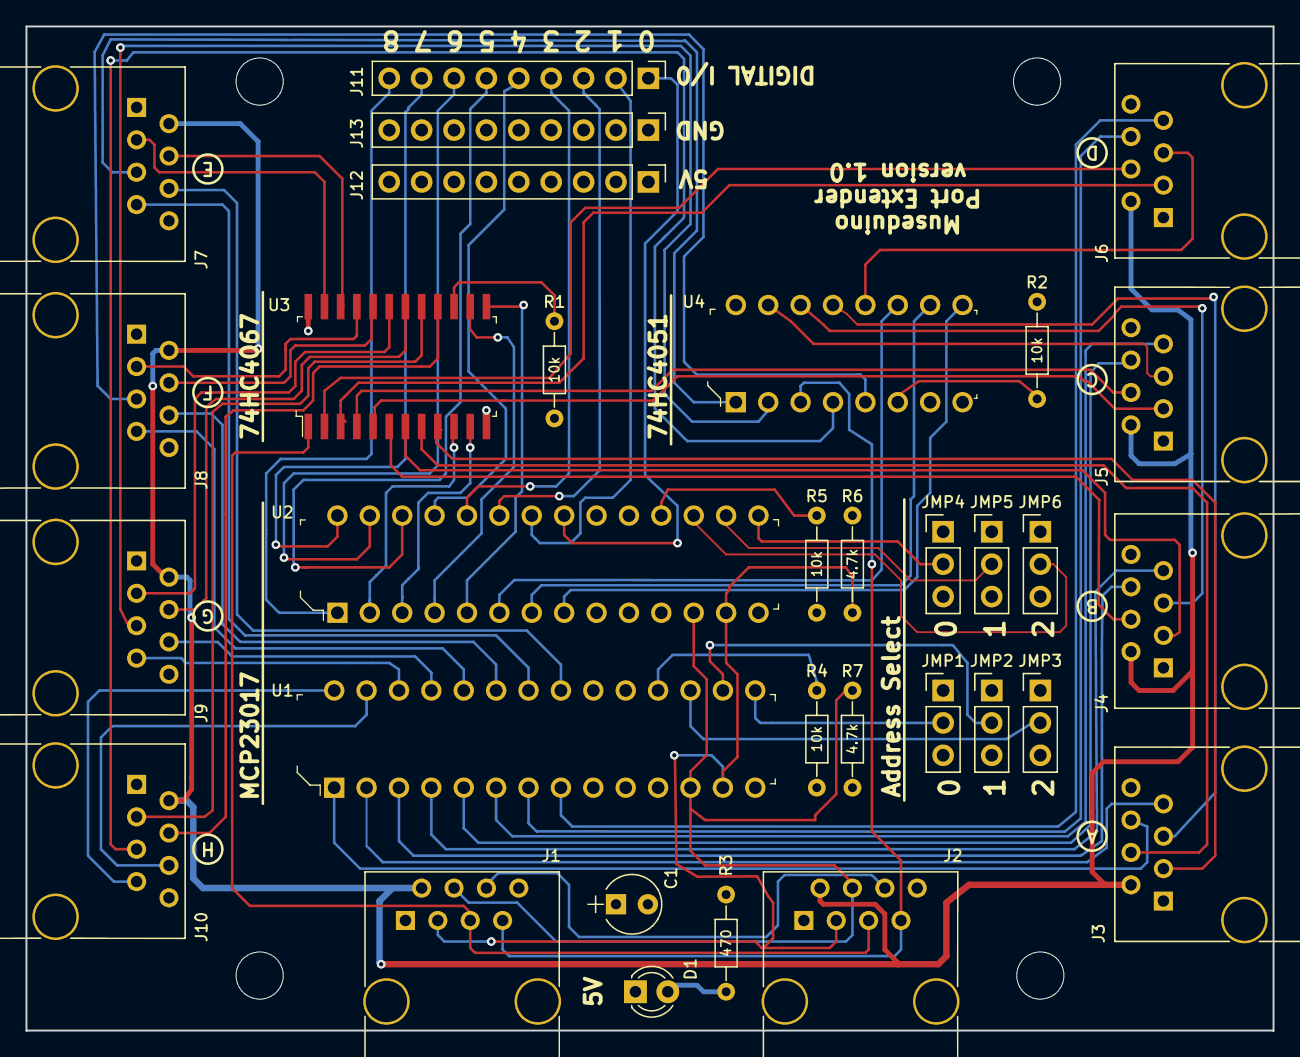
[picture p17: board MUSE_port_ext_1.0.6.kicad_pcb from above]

Board: 4 copper layers, 97.8 x 78.7 mm, 32 parts (0 on the bottom side), 75 nets.

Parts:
C1: 0.1; CP_Radial_Tantal_D4.5mm_P2.50mm
D1: LED; LED_D3.0mm
J1, J2, J3, J4, J5, J6, J7, J8, J9, J10: RJ45_01X08; RJ45_8
J11, J12, J13: Conn_01x09; Pin_Header_Straight_1x09_Pitch2.54mm
JMP1, JMP2, JMP3, JMP4, JMP5, JMP6: Conn_01x03; Pin_Header_Straight_1x03_Pitch2.54mm
R1, R2, R4, R5: 10K; R_Axial_DIN0204_L3.6mm_D1.6mm_P7.62mm_Horizontal
R3: 470; R_Axial_DIN0204_L3.6mm_D1.6mm_P7.62mm_Horizontal
R6, R7: 4.7K; R_Axial_DIN0204_L3.6mm_D1.6mm_P7.62mm_Horizontal
U1, U2: MCP23017-E_SP; DIP-28_W7.62mm
U3: CD74HC4067SM96; SSOP-24_W5.30mm
U4: CD74HC4051E; DIP-16_W7.62mm

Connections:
+3V3: J1.2, J2.2, J3.2, J4.2, J5.2, J6.2, J7.2, J8.2, J9.2, J10.2
+5V: C1.1, J1.1, J2.1, J3.1, J4.1, J5.1, J6.1, J7.1, J8.1, J9.1, J10.1, J12.1, J12.2, J12.3, J12.4, J12.5, J12.6, J12.7, J12.8, J12.9, JMP1.1, JMP2.1, JMP3.1, JMP4.1, JMP5.1, JMP6.1, R3.1, R4.1, R5.1, R6.1, R7.1, U1.9, U2.9, U3.24, U4.16
A1_OUT1: J3.3, U3.9
A1_OUT2: J4.3, U3.7
A1_OUT3: J5.3, U3.5
A1_OUT4: J6.3, U3.3
A1_OUT5: J7.3, U3.23
A1_OUT6: J8.3, U3.21
A1_OUT7: J9.3, U3.19
A1_OUT8: J10.3, U3.17
A2_OUT1: J3.4, U3.8
A2_OUT2: J4.4, U3.6
A2_OUT3: J5.4, U3.4
A2_OUT4: J6.4, U3.2
A2_OUT5: J7.4, U3.22
A2_OUT6: J8.4, U3.20
A2_OUT7: J9.4, U3.18
A2_OUT8: J10.4, U3.16
AMUX_8_S0: U2.6, U4.11
AMUX_8_S1: U2.7, U4.10
AMUX_8_S2: U2.8, U4.9
AMUX_16_COM_IN: J1.5, J2.5, U3.1
AMUX_16_S0: U2.2, U3.10
AMUX_16_S1: U2.3, U3.11
AMUX_16_S2: U2.4, U3.14
AMUX_16_S3: U2.5, U3.13
D1_OUT1: J3.6, U1.1
D1_OUT2: J4.6, U1.3
D1_OUT3: J5.6, U1.5
D1_OUT4: J6.6, U1.7
D1_OUT5: J7.6, U1.21
D1_OUT6: J8.6, U1.23
D1_OUT7: J9.6, U1.25
D1_OUT8: J10.6, U1.27
D2_INP: J1.6, J2.6
D2_OUT1: J3.7, U1.2
D2_OUT2: J4.7, U1.4
D2_OUT3: J5.7, U1.6
D2_OUT4: J6.7, U1.8
D2_OUT5: J7.7, U1.22
D2_OUT6: J8.7, U1.24
D2_OUT7: J9.7, U1.26
D2_OUT8: J10.7, U1.28
GND: C1.2, D1.1, J1.8, J2.8, J3.8, J4.8, J5.8, J6.8, J7.8, J8.8, J9.8, J10.8, J13.1, J13.2, J13.3, J13.4, J13.5, J13.6, J13.7, J13.8, J13.9, JMP1.3, JMP2.3, JMP3.3, JMP4.3, JMP5.3, JMP6.3, R1.2, R2.2, U1.10, U2.10, U3.12, U4.7
HDR_D1: J11.1, U2.21
HDR_D2: J11.2, U2.22
HDR_D3: J11.3, U2.23
HDR_D4: J11.4, U2.24
HDR_D5: J11.5, U2.25
HDR_D6: J11.6, U2.26
HDR_D7: J11.7, U2.27
HDR_D8: J11.8, U2.28
HDR_D9: J11.9, U2.1
unnamed: D1.2, R3.2
unnamed: R1.1, U3.15
unnamed: R2.1, U4.6
unnamed: R4.2, U1.18
unnamed: R5.2, U2.18
PWM_COM_OUT: J1.7, J2.7, U4.3
PWM_OUT1: J3.5, U4.13
PWM_OUT2: J4.5, U4.14
PWM_OUT3: J5.5, U4.15
PWM_OUT4: J6.5, U4.12
PWM_OUT5: J7.5, U4.1
PWM_OUT6: J8.5, U4.5
PWM_OUT7: J9.5, U4.2
PWM_OUT8: J10.5, U4.4
SCL: J1.4, J2.4, R7.2, U1.12, U2.12
SDA: J1.3, J2.3, R6.2, U1.13, U2.13
U1_A0: JMP1.2, U1.15
U1_A1: JMP2.2, U1.16
U1_A2: JMP3.2, U1.17
U2_A0: JMP4.2, U2.15
U2_A1: JMP5.2, U2.16
U2_A2: JMP6.2, U2.17

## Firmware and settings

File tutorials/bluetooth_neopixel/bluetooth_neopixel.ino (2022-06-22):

/*neopixel setup*/
#include <Adafruit_NeoPixel.h>
#include <avr/power.h>

// Which pin on the Arduino is connected to the NeoPixels?
// On a Trinket or Gemma we suggest changing this to 1
#define PIN           6

// How many NeoPixels are attached to the Arduino?
#define NUMPIXELS      30

// When we setup the NeoPixel library, we tell it how many pixels, and which pin to use to send signals.
// Note that for older NeoPixel strips you might need to change the third parameter--see the strandtest
// example for more information on possible values.
Adafruit_NeoPixel strip = Adafruit_NeoPixel(NUMPIXELS, PIN, NEO_GRB + NEO_KHZ800);


/*********************************************************************
 This is an example for our nRF51822 based Bluefruit LE modules

 Pick one up today in the adafruit shop!

 Adafruit invests time and resources providing this open source code,
 please support Adafruit and open-source hardware by purchasing
 products from Adafruit!

 MIT license, check LICENSE for more information
 All text above, and the splash screen below must be included in
 any redistribution
*********************************************************************/

#include <string.h>
#include <Arduino.h>
#include <SPI.h>
#if not defined (_VARIANT_ARDUINO_DUE_X_) && not defined (_VARIANT_ARDUINO_ZERO_)
  #include <SoftwareSerial.h>
#endif

#include "Adafruit_BLE.h"
#include "Adafruit_BluefruitLE_SPI.h"
#include "Adafruit_BluefruitLE_UART.h"

#include "BluefruitConfig.h"

/*=========================================================================
    APPLICATION SETTINGS

    FACTORYRESET_ENABLE       Perform a factory reset when running this sketch
   
                              Enabling this will put your Bluefruit LE module
                              in a 'known good' state and clear any config
                              data set in previous sketches or projects, so
                              running this at least once is a good idea.
   
                              When deploying your project, however, you will
                              want to disable factory reset by setting this
                              value to 0.  If you are making changes to your
                              Bluefruit LE device via AT commands, and those
                              changes aren't persisting across resets, this
                              is the reason why.  Factory reset will erase
                              the non-volatile memory where config data is
                              stored, setting it back to factory default
                              values.
       
                              Some sketches that require you to bond to a
                              central device (HID mouse, keyboard, etc.)
                              won't work at all with this feature enabled
                              since the factory reset will clear all of the
                              bonding data stored on the chip, meaning the
                              central device won't be able to reconnect.
    MINIMUM_FIRMWARE_VERSION  Minimum firmware version to have some new features
    MODE_LED_BEHAVIOUR        LED activity, valid options are
                              "DISABLE" or "MODE" or "BLEUART" or
                              "HWUART"  or "SPI"  or "MANUAL"
    -----------------------------------------------------------------------*/
    #define FACTORYRESET_ENABLE         1
    #define MINIMUM_FIRMWARE_VERSION    "0.6.6"
    #define MODE_LED_BEHAVIOUR          "MODE"
/*=========================================================================*/

// Create the bluefruit object, either software serial...uncomment these lines
/*
SoftwareSerial bluefruitSS = SoftwareSerial(BLUEFRUIT_SWUART_TXD_PIN, BLUEFRUIT_SWUART_RXD_PIN);

Adafruit_BluefruitLE_UART ble(bluefruitSS, BLUEFRUIT_UART_MODE_PIN,
                      BLUEFRUIT_UART_CTS_PIN, BLUEFRUIT_UART_RTS_PIN);
*/

/* ...or hardware serial, which does not need the RTS/CTS pins. Uncomment this line */
// Adafruit_BluefruitLE_UART ble(BLUEFRUIT_HWSERIAL_NAME, BLUEFRUIT_UART_MODE_PIN);

/* ...hardware SPI, using SCK/MOSI/MISO hardware SPI pins and then user selected CS/IRQ/RST */
Adafruit_BluefruitLE_SPI ble(BLUEFRUIT_SPI_CS, BLUEFRUIT_SPI_IRQ, BLUEFRUIT_SPI_RST);

/* ...software SPI, using SCK/MOSI/MISO user-defined SPI pins and then user selected CS/IRQ/RST */
//Adafruit_BluefruitLE_SPI ble(BLUEFRUIT_SPI_SCK, BLUEFRUIT_SPI_MISO,
//                             BLUEFRUIT_SPI_MOSI, BLUEFRUIT_SPI_CS,
//                             BLUEFRUIT_SPI_IRQ, BLUEFRUIT_SPI_RST);


// A small helper
void error(const __FlashStringHelper*err) {
  Serial.println(err);
  while (1);
}

// function prototypes over in packetparser.cpp
uint8_t readPacket(Adafruit_BLE *ble, uint16_t timeout);
float parsefloat(uint8_t *buffer);
void printHex(const uint8_t * data, const uint32_t numBytes);

// the packet buffer
extern uint8_t packetbuffer[];


/**************************************************************************/
/*!
    @brief  Sets up the HW an the BLE module (this function is called
            automatically on startup)
*/
/**************************************************************************/
void setup(void)
{
  while (!Serial);  // required for Flora & Micro
  delay(500);

  Serial.begin(115200);
  Serial.println(F("Adafruit Bluefruit App Controller Example"));
  Serial.println(F("-----------------------------------------"));

  /* Initialise the module */
  Serial.print(F("Initialising the Bluefruit LE module: "));

  if ( !ble.begin(VERBOSE_MODE) )
  {
    error(F("Couldn't find Bluefruit, make sure it's in CoMmanD mode & check wiring?"));
  }
  Serial.println( F("OK!") );

  if ( FACTORYRESET_ENABLE )
  {
    /* Perform a factory reset to make sure everything is in a known state */
    Serial.println(F("Performing a factory reset: "));
    if ( ! ble.factoryReset() ){
      error(F("Couldn't factory reset"));
    }
  }


  /* Disable command echo from Bluefruit */
  ble.echo(false);

  Serial.println("Requesting Bluefruit info:");
  /* Print Bluefruit information */
  ble.info();

  Serial.println(F("Please use Adafruit Bluefruit LE app to connect in Controller mode"));
  Serial.println(F("Then activate/use the sensors, color picker, game controller, etc!"));
  Serial.println();

  ble.verbose(false);  // debug info is a little annoying after this point!

  /* Wait for connection */
  while (! ble.isConnected()) {
      delay(500);
  }

  Serial.println(F("******************************"));

  // LED Activity command is only supported from 0.6.6
  if ( ble.isVersionAtLeast(MINIMUM_FIRMWARE_VERSION) )
  {
    // Change Mode LED Activity
    Serial.println(F("Change LED activity to " MODE_LED_BEHAVIOUR));
    ble.sendCommandCheckOK("AT+HWModeLED=" MODE_LED_BEHAVIOUR);
  }

  // Set Bluefruit to DATA mode
  Serial.println( F("Switching to DATA mode!") );
  ble.setMode(BLUEFRUIT_MODE_DATA);

  Serial.println(F("******************************"));
  
  strip.begin();
  strip.show(); // Initialize all pixels to 'off'

}

/**************************************************************************/
/*!
    @brief  Constantly poll for new command or response data
*/
/**************************************************************************/
void loop(void)
{
  /* Wait for new data to arrive */
  uint8_t len = readPacket(&ble, BLE_READPACKET_TIMEOUT);
  if (len == 0) return;

  /* Got a packet! */
   printHex(packetbuffer, len);

  // Color
  if (packetbuffer[1] == 'C') {
    uint8_t red = packetbuffer[2];
    uint8_t green = packetbuffer[3];
    uint8_t blue = packetbuffer[4];
    Serial.print ("RGB #");
    if (red < 0x10) Serial.print("0");
    Serial.print(red, HEX);
    if (green < 0x10) Serial.print("0");
    Serial.print(green, HEX);
    if (blue < 0x10) Serial.print("0");
    Serial.println(blue, HEX);
    
    colorWipe(strip.Color(red, green, blue), 50); //set color

  }

  // Buttons
  if (packetbuffer[1] == 'B') {
    uint8_t buttnum = packetbuffer[2] - '0';
    boolean pressed = packetbuffer[3] - '0';
    Serial.print ("Button "); Serial.print(buttnum);
    if (pressed) {
      Serial.println(" pressed");
    } else {
      Serial.println(" released");
    }
  }

  // GPS Location
  if (packetbuffer[1] == 'L') {
    float lat, lon, alt;
    lat = parsefloat(packetbuffer+2);
    lon = parsefloat(packetbuffer+6);
    alt = parsefloat(packetbuffer+10);
    Serial.print("GPS Location\t");
    Serial.print("Lat: "); Serial.print(lat, 4); // 4 digits of precision!
    Serial.print('\t');
    Serial.print("Lon: "); Serial.print(lon, 4); // 4 digits of precision!
    Serial.print('\t');
    Serial.print(alt, 4); Serial.println(" meters");
  }

  // Accelerometer
  if (packetbuffer[1] == 'A') {
    float x, y, z;
    x = parsefloat(packetbuffer+2);
    y = parsefloat(packetbuffer+6);
    z = parsefloat(packetbuffer+10);
    Serial.print("Accel\t");
    Serial.print(x); Serial.print('\t');
    Serial.print(y); Serial.print('\t');
    Serial.print(z); Serial.println();
  }

  // Magnetometer
  if (packetbuffer[1] == 'M') {
    float x, y, z;
    x = parsefloat(packetbuffer+2);
    y = parsefloat(packetbuffer+6);
    z = parsefloat(packetbuffer+10);
    Serial.print("Mag\t");
    Serial.print(x); Serial.print('\t');
    Serial.print(y); Serial.print('\t');
    Serial.print(z); Serial.println();
  }

  // Gyroscope
  if (packetbuffer[1] == 'G') {
    float x, y, z;
    x = parsefloat(packetbuffer+2);
    y = parsefloat(packetbuffer+6);
    z = parsefloat(packetbuffer+10);
    Serial.print("Gyro\t");
    Serial.print(x); Serial.print('\t');
    Serial.print(y); Serial.print('\t');
    Serial.print(z); Serial.println();
  }

  // Quaternions
  if (packetbuffer[1] == 'Q') {
    float x, y, z, w;
    x = parsefloat(packetbuffer+2);
    y = parsefloat(packetbuffer+6);
    z = parsefloat(packetbuffer+10);
    w = parsefloat(packetbuffer+14);
    Serial.print("Quat\t");
    Serial.print(x); Serial.print('\t');
    Serial.print(y); Serial.print('\t');
    Serial.print(z); Serial.print('\t');
    Serial.print(w); Serial.println();
  }
}


// Fill the dots one after the other with a color
void colorWipe(uint32_t c, uint8_t wait) {
  for(uint16_t i=0; i< NUMPIXELS; i++) {
      strip.setPixelColor(i, c);
      strip.show();
      delay(wait);
  }
}

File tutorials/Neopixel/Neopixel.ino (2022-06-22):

#include <Adafruit_NeoPixel.h>
#include <avr/power.h>

#define NUMPIXEL 30
#define PIN 6

// Parameter 1 = number of pixels in strip
// Parameter 2 = Arduino pin number (most are valid)
// Parameter 3 = pixel type flags, add together as needed:
//   NEO_KHZ800  800 KHz bitstream (most NeoPixel products w/WS2812 LEDs)
//   NEO_KHZ400  400 KHz (classic 'v1' (not v2) FLORA pixels, WS2811 drivers)
//   NEO_GRB     Pixels are wired for GRB bitstream (most NeoPixel products)
//   NEO_RGB     Pixels are wired for RGB bitstream (v1 FLORA pixels, not v2)
Adafruit_NeoPixel strip = Adafruit_NeoPixel(NUMPIXEL, PIN, NEO_GRB + NEO_KHZ800);

// IMPORTANT: To reduce NeoPixel burnout risk, add 1000 uF capacitor across
// pixel power leads, add 300 - 500 Ohm resistor on first pixel's data input
// and minimize distance between Arduino and first pixel.  Avoid connecting
// on a live circuit...if you must, connect GND first.

void setup() {
  strip.begin();
  strip.show(); // Initialize all pixels to 'off'
}

void loop() {
  // Some example procedures showing how to display to the pixels:
  colorWipe(strip.Color(255, 0, 0), 50); // Red
  colorWipe(strip.Color(0, 255, 0), 50); // Green
  colorWipe(strip.Color(0, 0, 255), 50); // Blue
  // Send a theater pixel chase in...
  theaterChase(strip.Color(127, 127, 127), 50); // White
  theaterChase(strip.Color(127,   0,   0), 50); // Red
  theaterChase(strip.Color(  0,   0, 127), 50); // Blue

  rainbow(20);
  rainbowCycle(20);
  theaterChaseRainbow(50);
}

// Fill the dots one after the other with a color
void colorWipe(uint32_t c, uint8_t wait) {
  for(uint16_t i=0; i<strip.numPixels(); i++) {
      strip.setPixelColor(i, c);
      strip.show();
      delay(wait);
  }
}

void rainbow(uint8_t wait) {
  uint16_t i, j;

  for(j=0; j<256; j++) {
    for(i=0; i<strip.numPixels(); i++) {
      strip.setPixelColor(i, Wheel((i+j) & 255));
    }
    strip.show();
    delay(wait);
  }
}

// Slightly different, this makes the rainbow equally distributed throughout
void rainbowCycle(uint8_t wait) {
  uint16_t i, j;

  for(j=0; j<256*5; j++) { // 5 cycles of all colors on wheel
    for(i=0; i< strip.numPixels(); i++) {
      strip.setPixelColor(i, Wheel(((i * 256 / strip.numPixels()) + j) & 255));
    }
    strip.show();
    delay(wait);
  }
}

//Theatre-style crawling lights.
void theaterChase(uint32_t c, uint8_t wait) {
  for (int j=0; j<10; j++) {  //do 10 cycles of chasing
    for (int q=0; q < 3; q++) {
      for (int i=0; i < strip.numPixels(); i=i+3) {
        strip.setPixelColor(i+q, c);    //turn every third pixel on
      }
      strip.show();
     
      delay(wait);
     
      for (int i=0; i < strip.numPixels(); i=i+3) {
        strip.setPixelColor(i+q, 0);        //turn every third pixel off
      }
    }
  }
}

//Theatre-style crawling lights with rainbow effect
void theaterChaseRainbow(uint8_t wait) {
  for (int j=0; j < 256; j++) {     // cycle all 256 colors in the wheel
    for (int q=0; q < 3; q++) {
        for (int i=0; i < strip.numPixels(); i=i+3) {
          strip.setPixelColor(i+q, Wheel( (i+j) % 255));    //turn every third pixel on
        }
        strip.show();
       
        delay(wait);
       
        for (int i=0; i < strip.numPixels(); i=i+3) {
          strip.setPixelColor(i+q, 0);        //turn every third pixel off
        }
    }
  }
}

// Input a value 0 to 255 to get a color value.
// The colours are a transition r - g - b - back to r.
uint32_t Wheel(byte WheelPos) {
  WheelPos = 255 - WheelPos;
  if(WheelPos < 85) {
   return strip.Color(255 - WheelPos * 3, 0, WheelPos * 3);
  } else if(WheelPos < 170) {
    WheelPos -= 85;
   return strip.Color(0, WheelPos * 3, 255 - WheelPos * 3);
  } else {
   WheelPos -= 170;
   return strip.Color(WheelPos * 3, 255 - WheelPos * 3, 0);
  }
}

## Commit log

2015-06-08 Create Button
2015-08-11 Create PWMServo
2016-10-04 PCB Schematic
2020-01-06 additional code samples
2020-01-06 pcb design files and schematics
    [MUSE_main_4.0.3.kicad_pcb, MUSE_main_4.0.3.sch, MUSE_port_ext_1.0.6-2018-10-17-11-59-49.sch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]
2022-07-15 update archive
    [MUSE_main_3.1_I2C-2022-07-15-12-11-08.sch, MUSE_main_3.1_I2C.kicad_pcb, MUSE_main_3.1_I2C.sch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]
2022-07-20 express pcb versions
    [Museduino v1.7 BOM.xlsx, museduino 4port v1.4.sch, museduino 4port v1.4a.sch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]
